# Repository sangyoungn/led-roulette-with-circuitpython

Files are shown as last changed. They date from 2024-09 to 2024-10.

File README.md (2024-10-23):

# LED Roulette with CircuitPython

This is a project to build an LED roulette with CircuitPython on EFR32xG24 Explorer Kit.

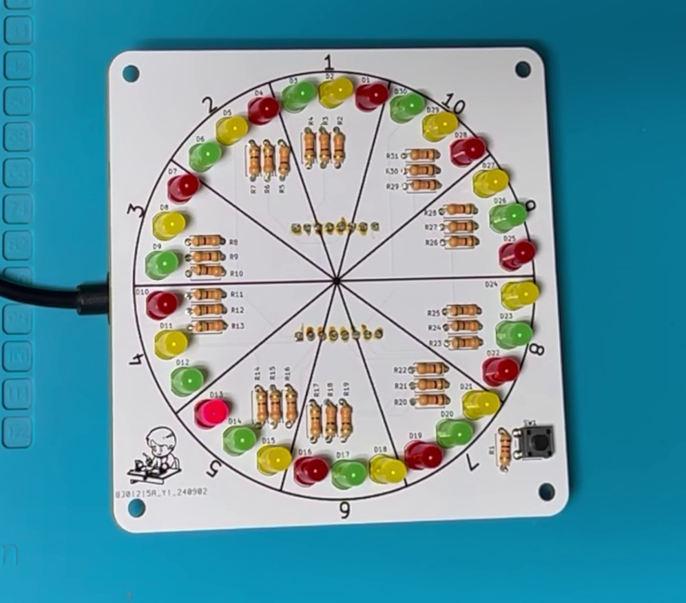
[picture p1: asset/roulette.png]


## Contents

"**hardware**" directory contains files for the hardware design including schematic and gerber output.
"**code**" directry contains scripts written in CircuitPython, which run on EFR32xG24 Explorer Kit.

## Directory Structure

.   
├── **hardware**   
|&nbsp;&nbsp;&nbsp;&nbsp;&nbsp;└── **roulette** (KiCad Design Directory)   
|&nbsp;&nbsp;&nbsp;&nbsp;&nbsp;&nbsp;&nbsp;&nbsp;&nbsp;&nbsp;├── **gerber** (PCB Gerber Plot Directory)   
|&nbsp;&nbsp;&nbsp;&nbsp;&nbsp;&nbsp;&nbsp;&nbsp;&nbsp;&nbsp;├── **pdf** (PCB PDF Polt Directory)   
|&nbsp;&nbsp;&nbsp;&nbsp;&nbsp;&nbsp;&nbsp;&nbsp;&nbsp;&nbsp;├── *roulette.dxf* (PCB Outline and Decoration Silk DXF)   
|&nbsp;&nbsp;&nbsp;&nbsp;&nbsp;&nbsp;&nbsp;&nbsp;&nbsp;&nbsp;├── *roulette.kicad_pcb* (PCB Design File)   
|&nbsp;&nbsp;&nbsp;&nbsp;&nbsp;&nbsp;&nbsp;&nbsp;&nbsp;&nbsp;├── *roulette.kicad_pro* (KiCad Project File)   
|&nbsp;&nbsp;&nbsp;&nbsp;&nbsp;&nbsp;&nbsp;&nbsp;&nbsp;&nbsp;├── *roulette.pdf* (PDF Plot File of Whole Schematic)   
|&nbsp;&nbsp;&nbsp;&nbsp;&nbsp;&nbsp;&nbsp;&nbsp;&nbsp;&nbsp;├── *roulette.kicad_sch* (Schematic File #1)   
|&nbsp;&nbsp;&nbsp;&nbsp;&nbsp;&nbsp;&nbsp;&nbsp;&nbsp;&nbsp;├── *LEDs.kicad_sch* (Schematic File #2)    
|&nbsp;&nbsp;&nbsp;&nbsp;&nbsp;&nbsp;&nbsp;&nbsp;&nbsp;&nbsp;└── *xg24_explorer_kit.kicad_sch* (Schematic File #3)   
└── **code**   
&nbsp;&nbsp;&nbsp;&nbsp;&nbsp;├── *code.py*   
&nbsp;&nbsp;&nbsp;&nbsp;&nbsp;└── *led_roulette.py*   

Refer to clips in the link for more information.

https://youtube.com/playlist?list=PLlT0qmKc0_5ddENmn3fNbMIVXvFqQTv2Z&si=PHfeczIfOtfNPaJ8

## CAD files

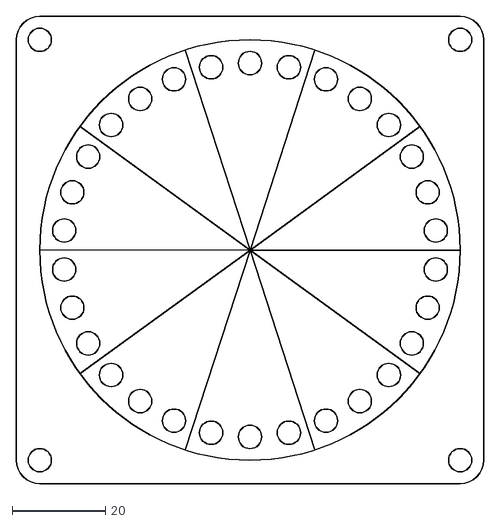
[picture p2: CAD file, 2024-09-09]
hardware/roulette/roulette.dxf
100.0 x 100.0

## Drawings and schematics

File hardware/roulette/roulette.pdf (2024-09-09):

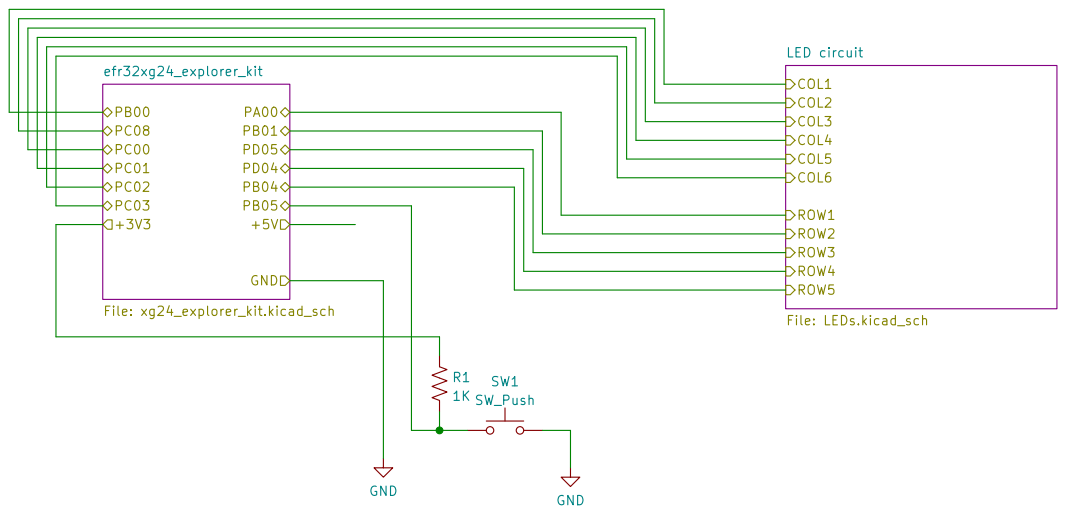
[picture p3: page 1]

File: roulette.kicad_sch Sheet: /
Id: 1/3 Title: LED Roulette

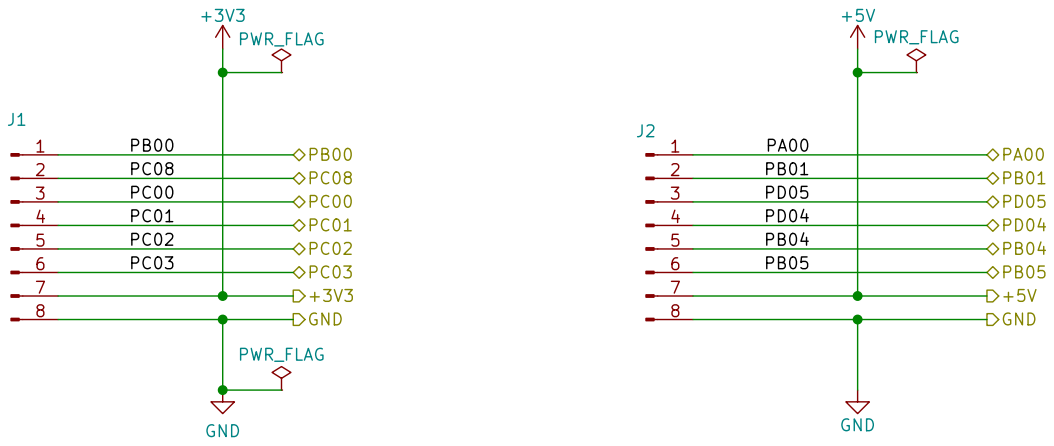
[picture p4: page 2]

Sheet: /efr32xg24_explorer_kit/
File: xg24_explorer_kit.kicad_sch
Id: 2/3 Title: EFR32xG24 Explorer Kit

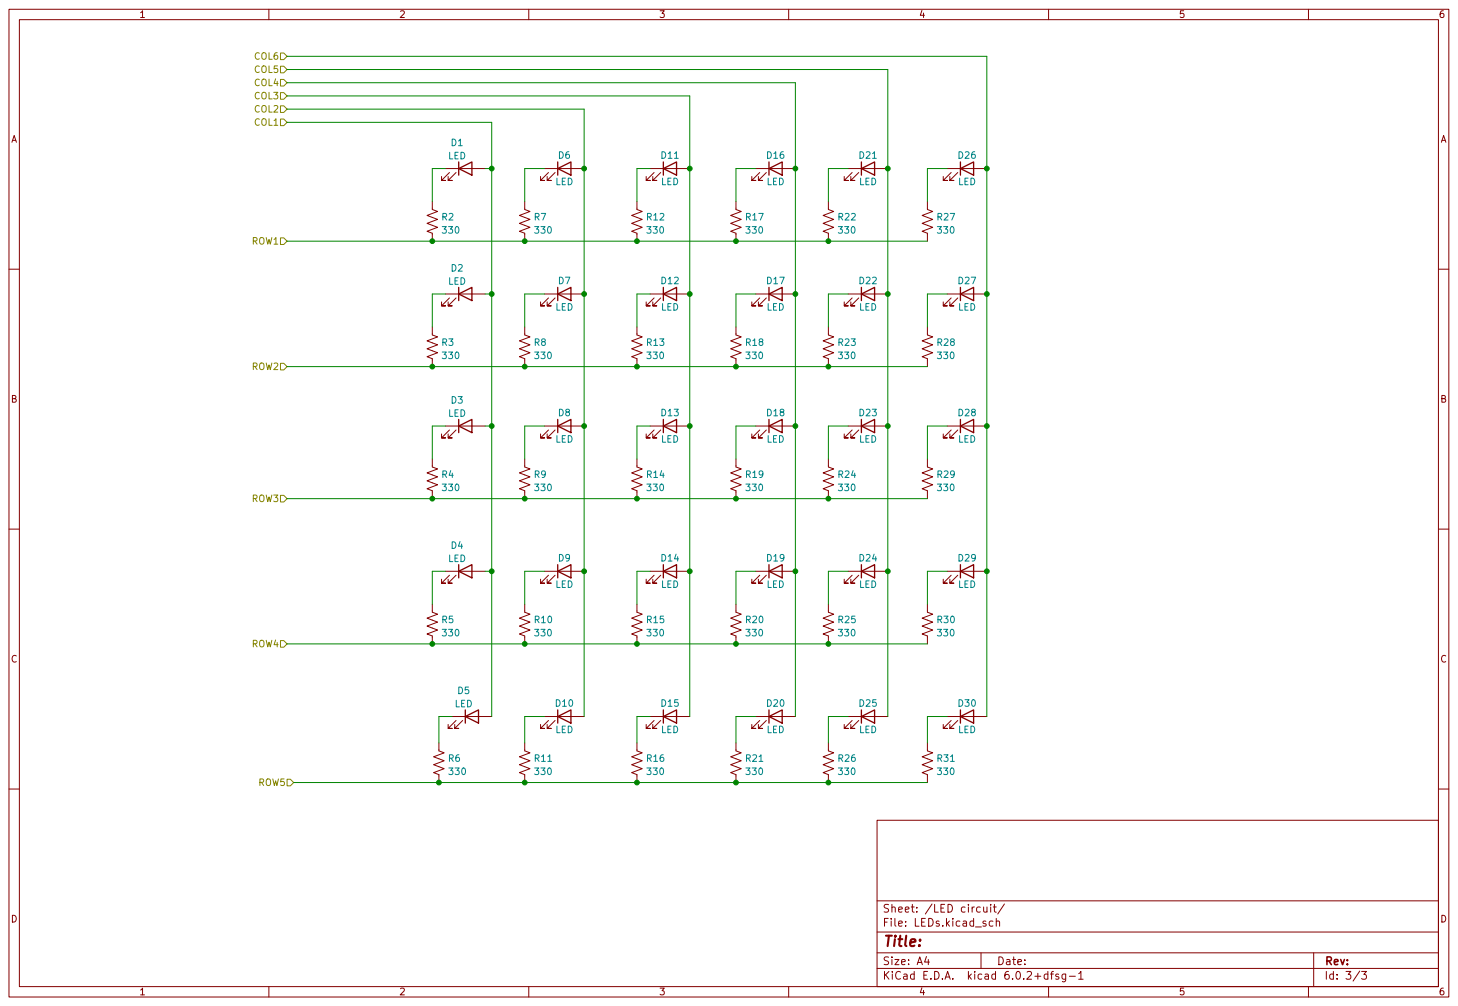
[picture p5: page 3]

File: LEDs.kicad_sch Sheet: /LED circuit/ R26

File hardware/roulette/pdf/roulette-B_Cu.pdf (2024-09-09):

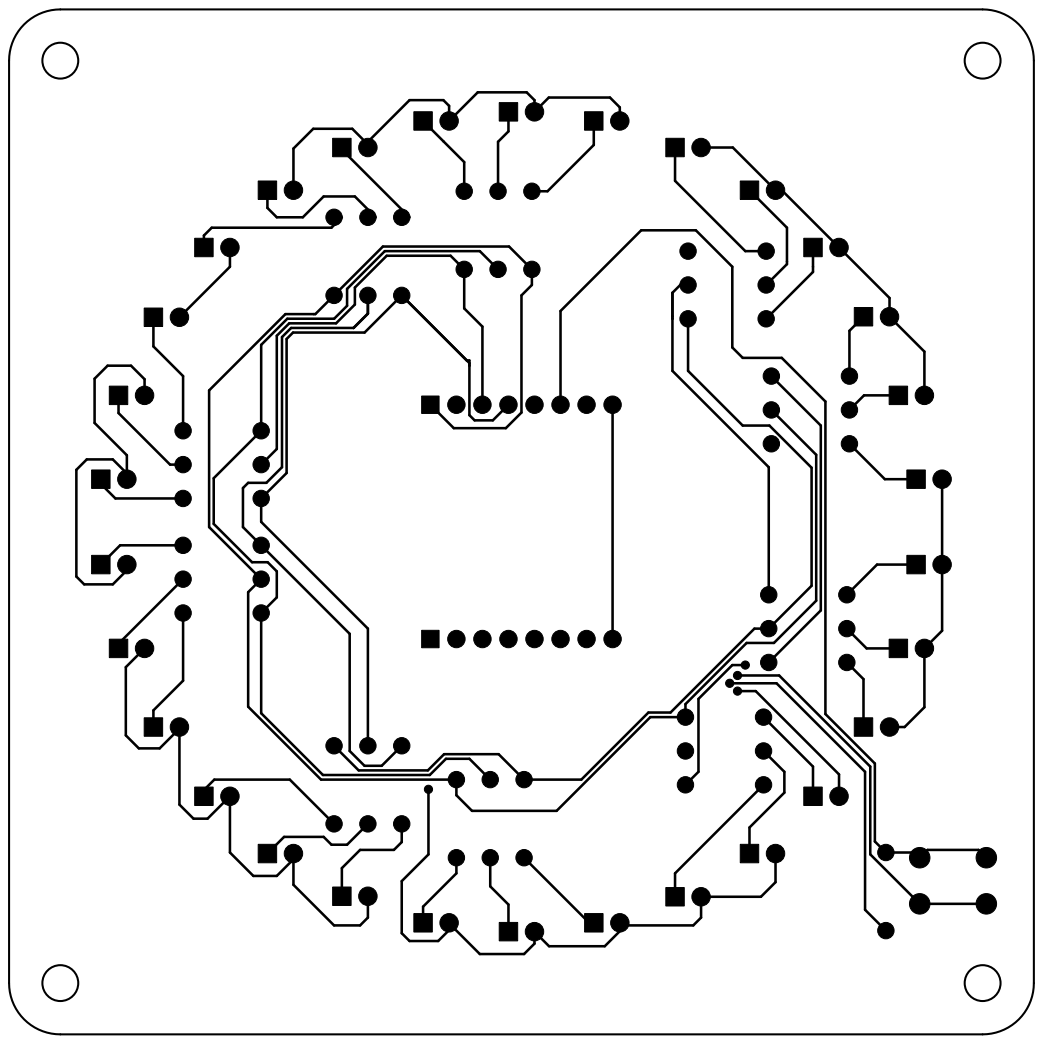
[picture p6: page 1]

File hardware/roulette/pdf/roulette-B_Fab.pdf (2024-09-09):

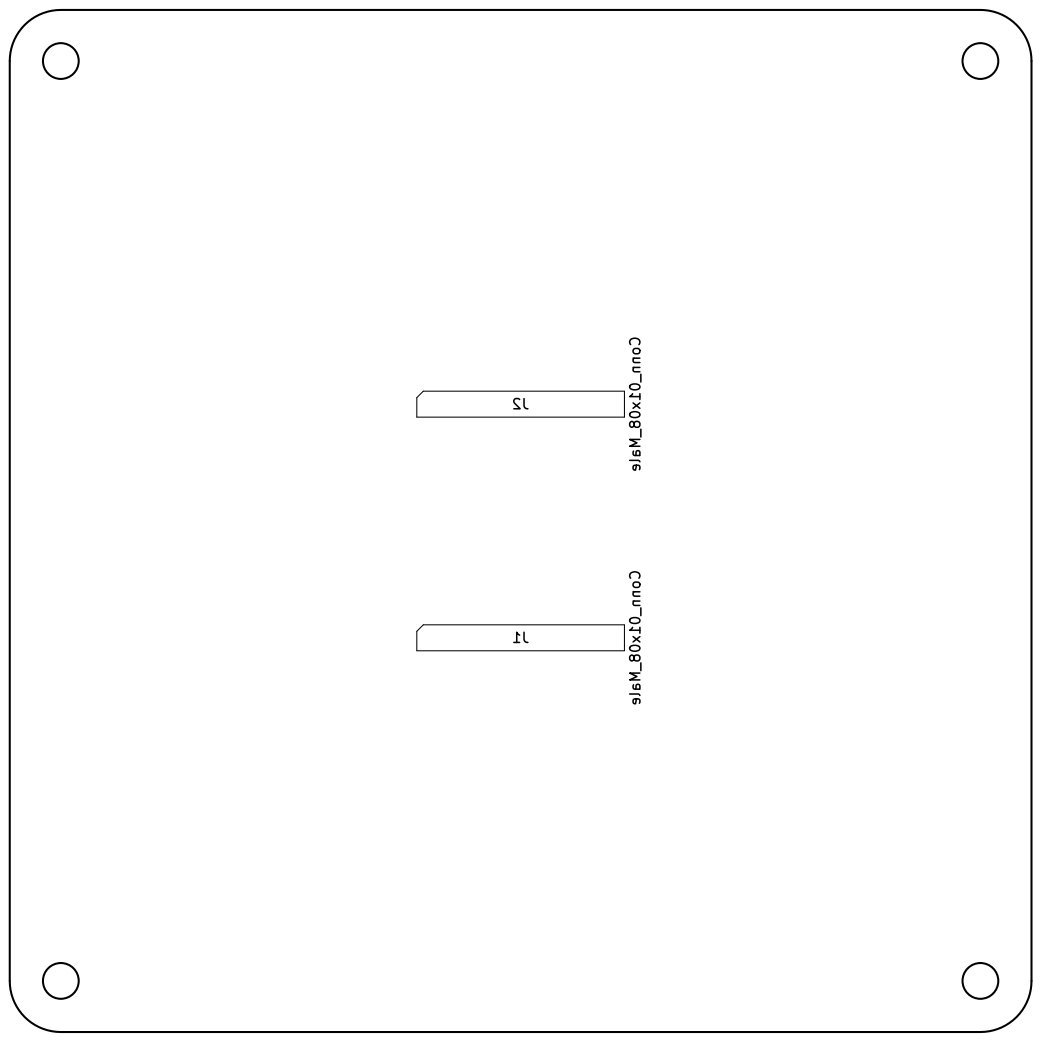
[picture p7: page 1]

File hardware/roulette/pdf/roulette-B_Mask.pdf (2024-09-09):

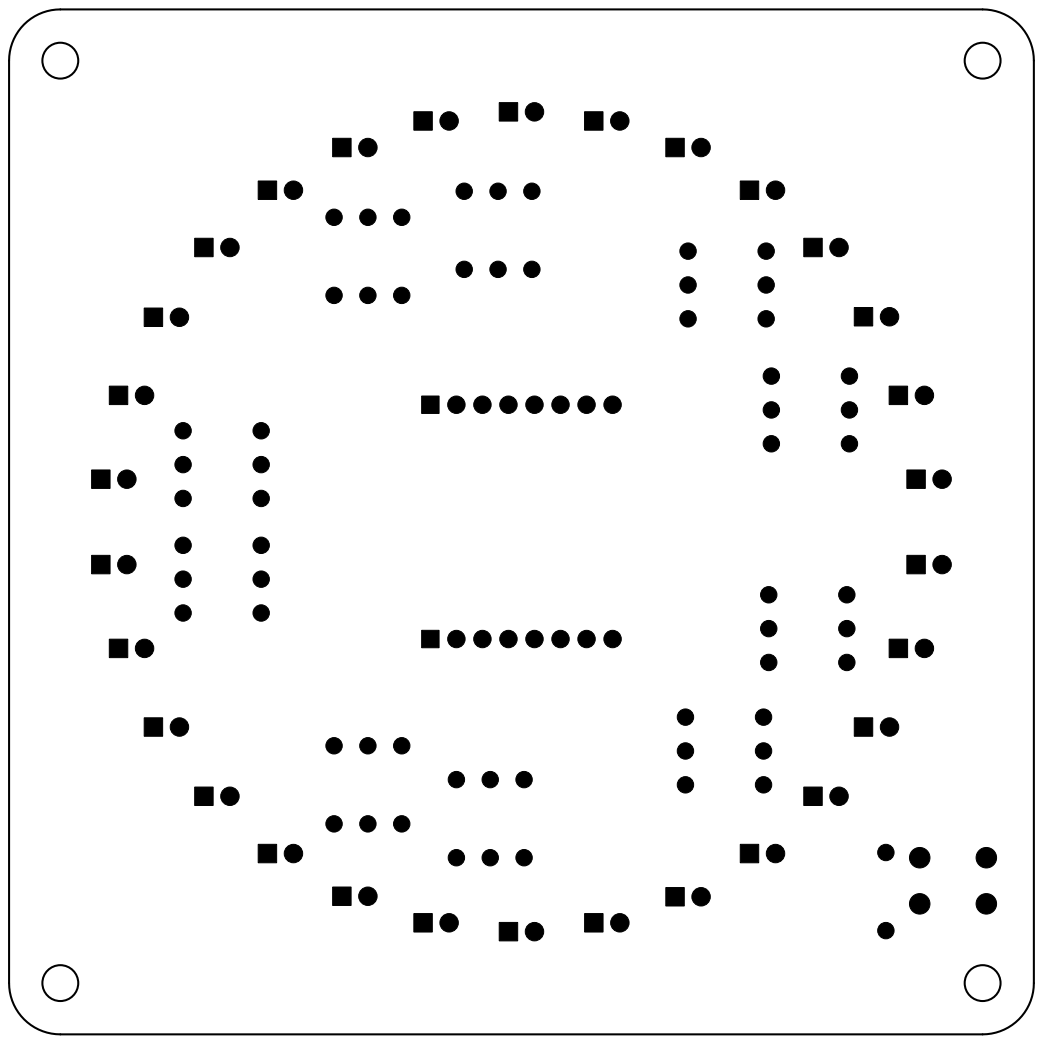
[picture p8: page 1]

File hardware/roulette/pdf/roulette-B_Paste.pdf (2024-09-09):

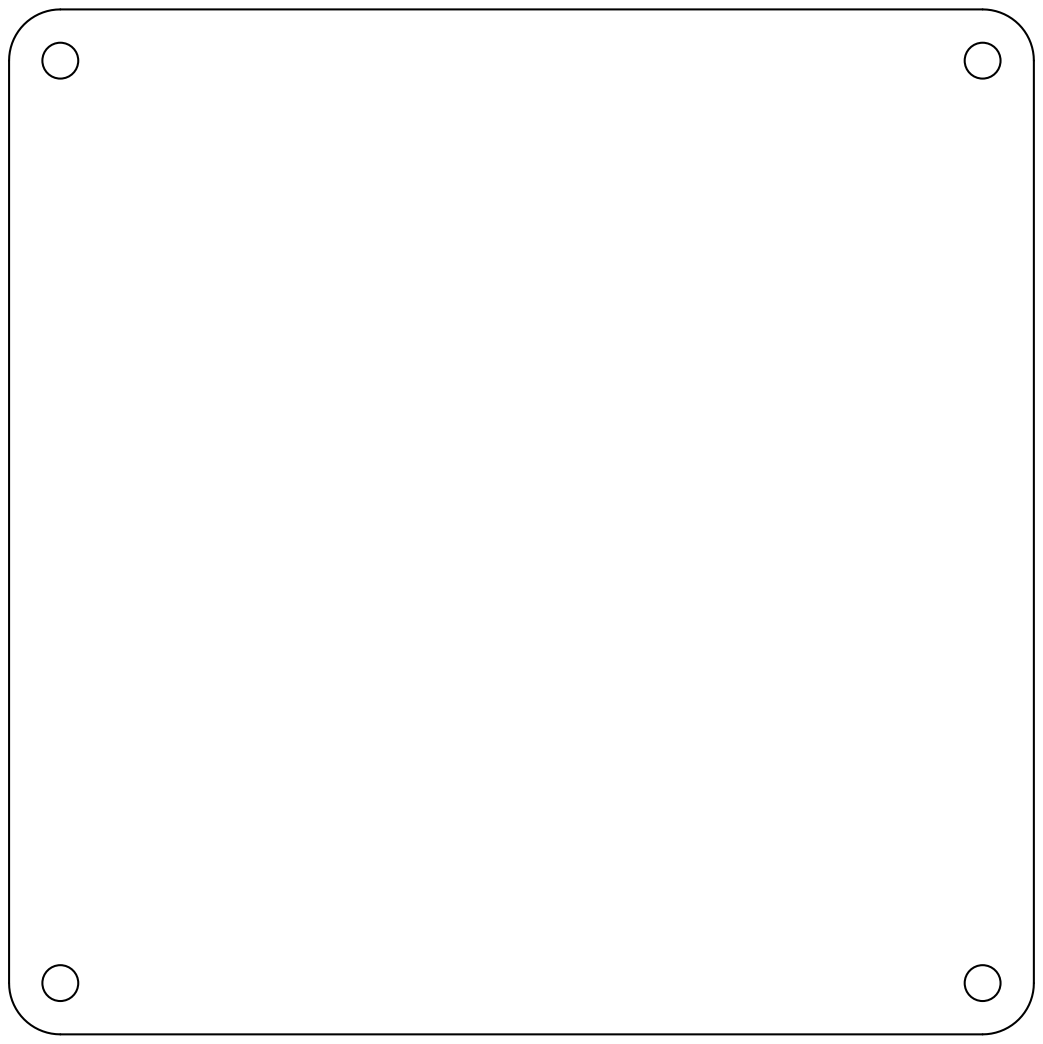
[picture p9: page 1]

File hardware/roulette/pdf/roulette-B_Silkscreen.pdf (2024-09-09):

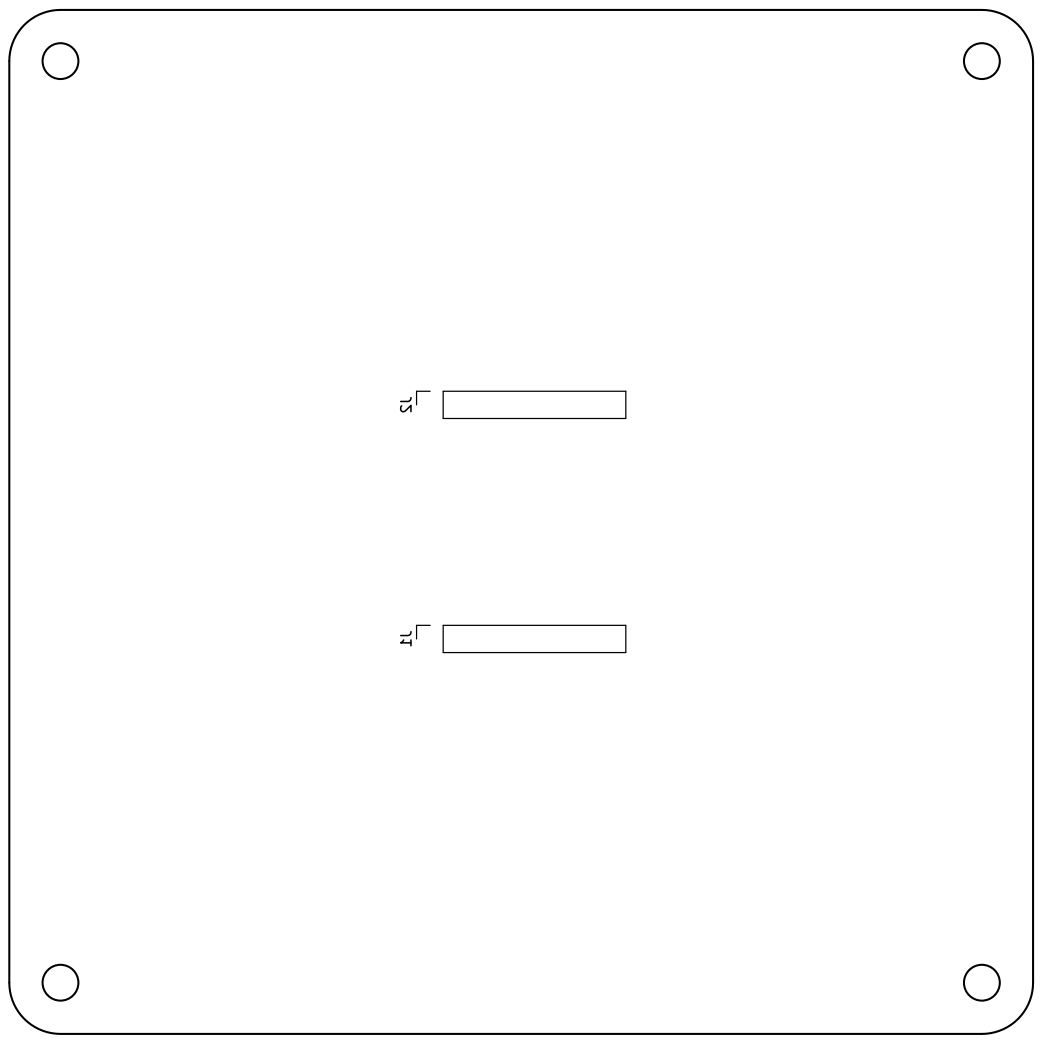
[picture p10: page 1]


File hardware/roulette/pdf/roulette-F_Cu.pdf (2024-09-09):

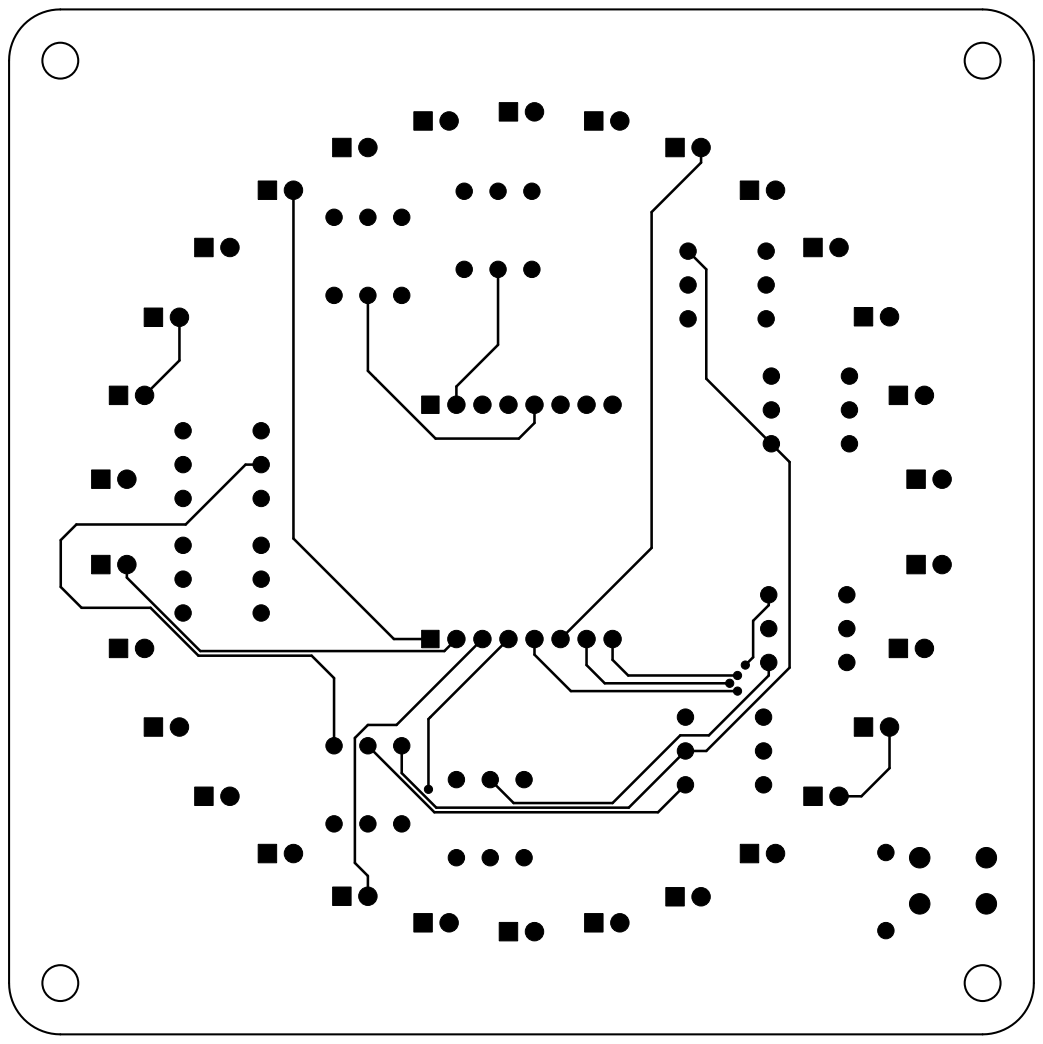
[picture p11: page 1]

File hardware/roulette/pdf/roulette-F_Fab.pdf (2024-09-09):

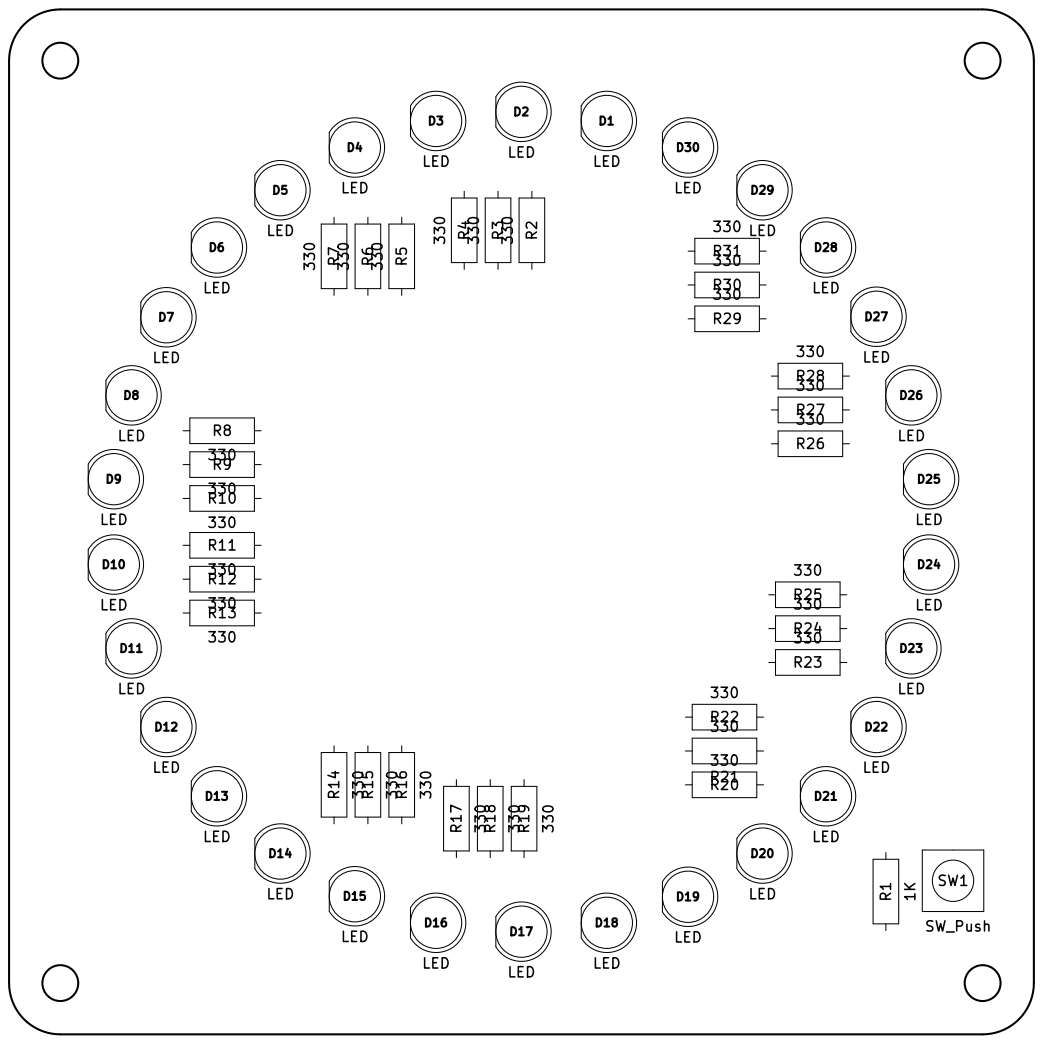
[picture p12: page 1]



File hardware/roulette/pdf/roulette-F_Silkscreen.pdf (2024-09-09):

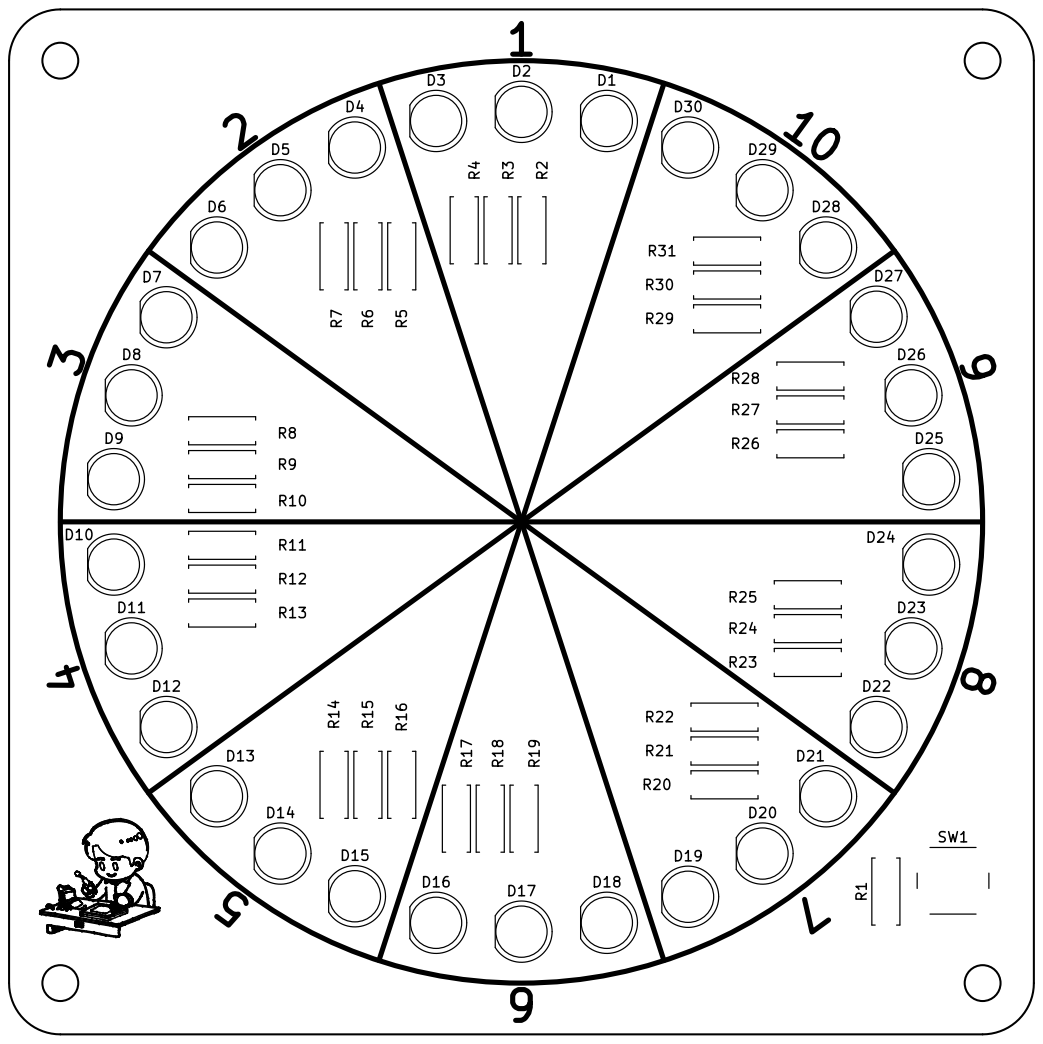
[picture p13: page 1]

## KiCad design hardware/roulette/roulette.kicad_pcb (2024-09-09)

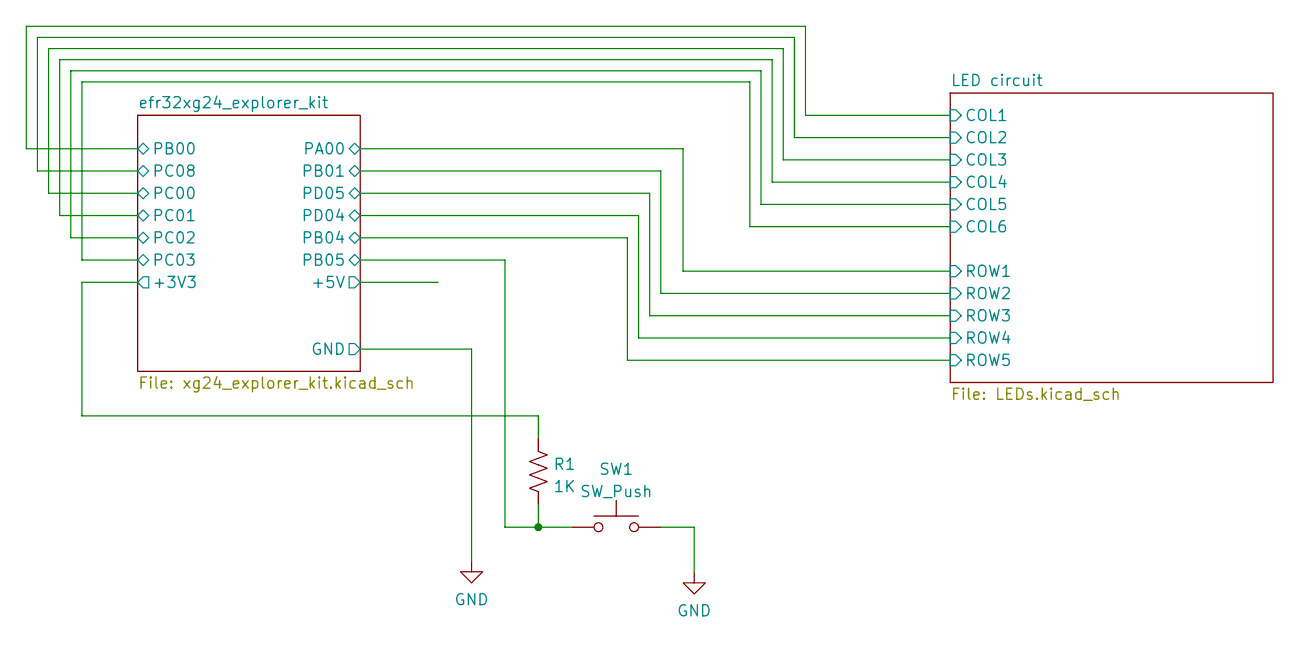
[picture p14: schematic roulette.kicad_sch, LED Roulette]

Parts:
R1: 1K; R_Axial_DIN0207_L6.3mm_D2.5mm_P7.62mm_Horizontal
SW1: SW_Push; SW_PUSH_6mm

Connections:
+3V3: R1.1; also elsewhere on the board
/efr32xg24_explorer_kit/PB05: R1.2, SW1.1; also elsewhere on the board
GND: SW1.2; also elsewhere on the board

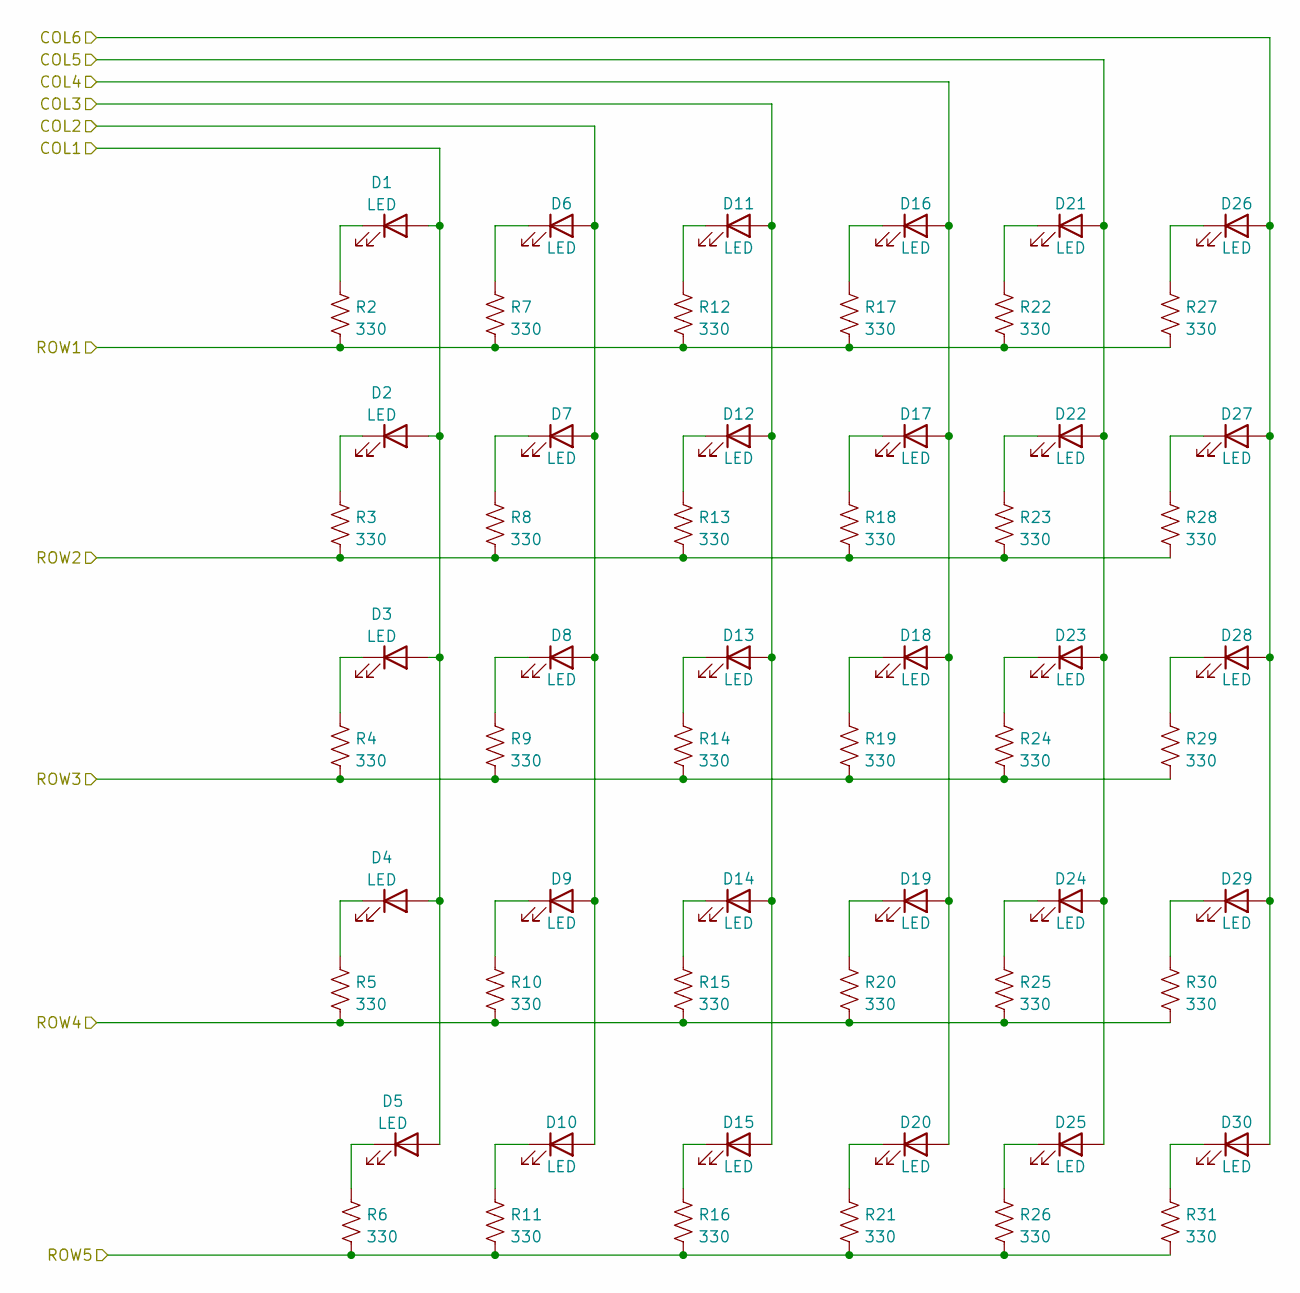
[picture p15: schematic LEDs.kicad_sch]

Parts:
D1, D2, D3, D4, D5, D6, D7, D8, D9, D10, D11, D12, D13, D14, D15, D16, D17, D18, D19, D20, D21, D22, D23, D24, D25, D26, D27, D28, D29, D30: LED; LED_D5.0mm
R2, R3, R4, R5, R6, R7, R8, R9, R10, R11, R12, R13, R14, R15, R16, R17, R18, R19, R20, R21, R22, R23, R24, R25, R26, R27, R28, R29, R30, R31: 330; R_Axial_DIN0207_L6.3mm_D2.5mm_P7.62mm_Horizontal

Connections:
/efr32xg24_explorer_kit/PA00: R2.2, R7.2, R12.2, R17.2, R22.2, R27.2; also elsewhere on the board
/efr32xg24_explorer_kit/PB00: D1.2 (A), D2.2 (A), D3.2 (A), D4.2 (A), D5.2 (A); also elsewhere on the board
/efr32xg24_explorer_kit/PB01: R3.2, R8.2, R13.2, R18.2, R23.2, R28.2; also elsewhere on the board
/efr32xg24_explorer_kit/PB04: R6.2, R11.2, R16.2, R21.2, R26.2, R31.2; also elsewhere on the board
/efr32xg24_explorer_kit/PC00: D11.2 (A), D12.2 (A), D13.2 (A), D14.2 (A), D15.2 (A); also elsewhere on the board
/efr32xg24_explorer_kit/PC01: D16.2 (A), D17.2 (A), D18.2 (A), D19.2 (A), D20.2 (A); also elsewhere on the board
/efr32xg24_explorer_kit/PC02: D21.2 (A), D22.2 (A), D23.2 (A), D24.2 (A), D25.2 (A); also elsewhere on the board
/efr32xg24_explorer_kit/PC03: D26.2 (A), D27.2 (A), D28.2 (A), D29.2 (A), D30.2 (A); also elsewhere on the board
/efr32xg24_explorer_kit/PC08: D6.2 (A), D7.2 (A), D8.2 (A), D9.2 (A), D10.2 (A); also elsewhere on the board
/efr32xg24_explorer_kit/PD04: R5.2, R10.2, R15.2, R20.2, R25.2, R30.2; also elsewhere on the board
/efr32xg24_explorer_kit/PD05: R4.2, R9.2, R14.2, R19.2, R24.2, R29.2; also elsewhere on the board
unnamed: D1.1 (K), R2.1
unnamed: D2.1 (K), R3.1
unnamed: D3.1 (K), R4.1
unnamed: D4.1 (K), R5.1
unnamed: D5.1 (K), R6.1
unnamed: D6.1 (K), R7.1
unnamed: D7.1 (K), R8.1
unnamed: D8.1 (K), R9.1
unnamed: D9.1 (K), R10.1
unnamed: D10.1 (K), R11.1
unnamed: D11.1 (K), R12.1
unnamed: D12.1 (K), R13.1
unnamed: D13.1 (K), R14.1
unnamed: D14.1 (K), R15.1
unnamed: D15.1 (K), R16.1
unnamed: D16.1 (K), R17.1
unnamed: D17.1 (K), R18.1
unnamed: D18.1 (K), R19.1
unnamed: D19.1 (K), R20.1
unnamed: D20.1 (K), R21.1
unnamed: D21.1 (K), R22.1
unnamed: D22.1 (K), R23.1
unnamed: D23.1 (K), R24.1
unnamed: D24.1 (K), R25.1
unnamed: D25.1 (K), R26.1
unnamed: D26.1 (K), R27.1
unnamed: D27.1 (K), R28.1
unnamed: D28.1 (K), R29.1
unnamed: D29.1 (K), R30.1
unnamed: D30.1 (K), R31.1

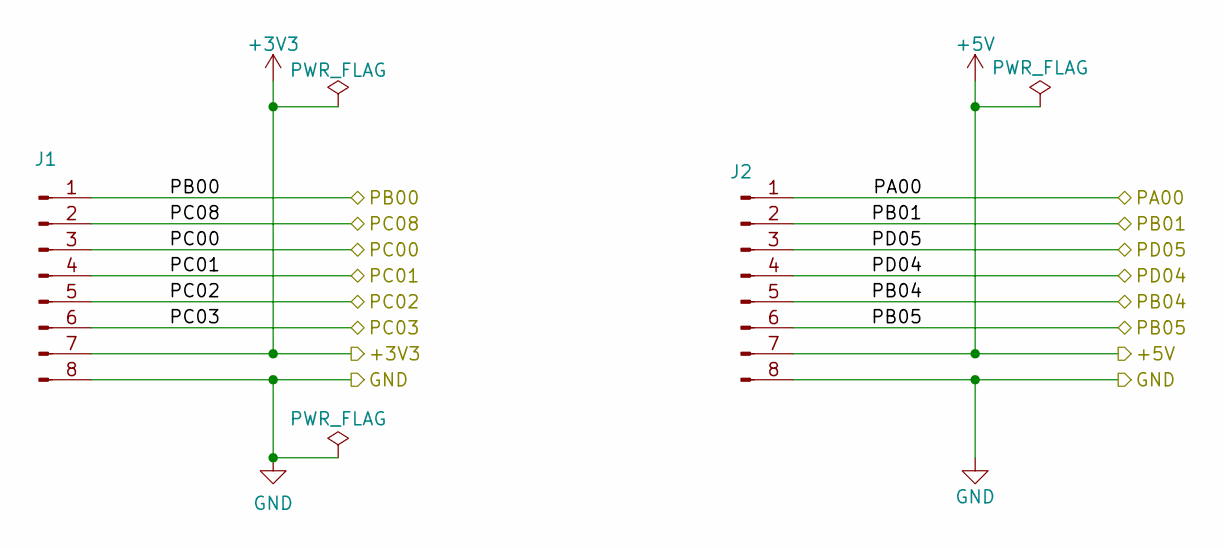
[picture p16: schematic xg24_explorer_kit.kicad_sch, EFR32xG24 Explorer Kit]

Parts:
J1, J2: Conn_01x08_Male; PinHeader_1x08_P2.54mm_Vertical

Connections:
+3V3: J1.7; also elsewhere on the board
+5V: J2.7
/efr32xg24_explorer_kit/PA00: J2.1; also elsewhere on the board
/efr32xg24_explorer_kit/PB00: J1.1; also elsewhere on the board
/efr32xg24_explorer_kit/PB01: J2.2; also elsewhere on the board
/efr32xg24_explorer_kit/PB04: J2.5; also elsewhere on the board
/efr32xg24_explorer_kit/PB05: J2.6; also elsewhere on the board
/efr32xg24_explorer_kit/PC00: J1.3; also elsewhere on the board
/efr32xg24_explorer_kit/PC01: J1.4; also elsewhere on the board
/efr32xg24_explorer_kit/PC02: J1.5; also elsewhere on the board
/efr32xg24_explorer_kit/PC03: J1.6; also elsewhere on the board
/efr32xg24_explorer_kit/PC08: J1.2; also elsewhere on the board
/efr32xg24_explorer_kit/PD04: J2.4; also elsewhere on the board
/efr32xg24_explorer_kit/PD05: J2.3; also elsewhere on the board
GND: J1.8, J2.8; also elsewhere on the board

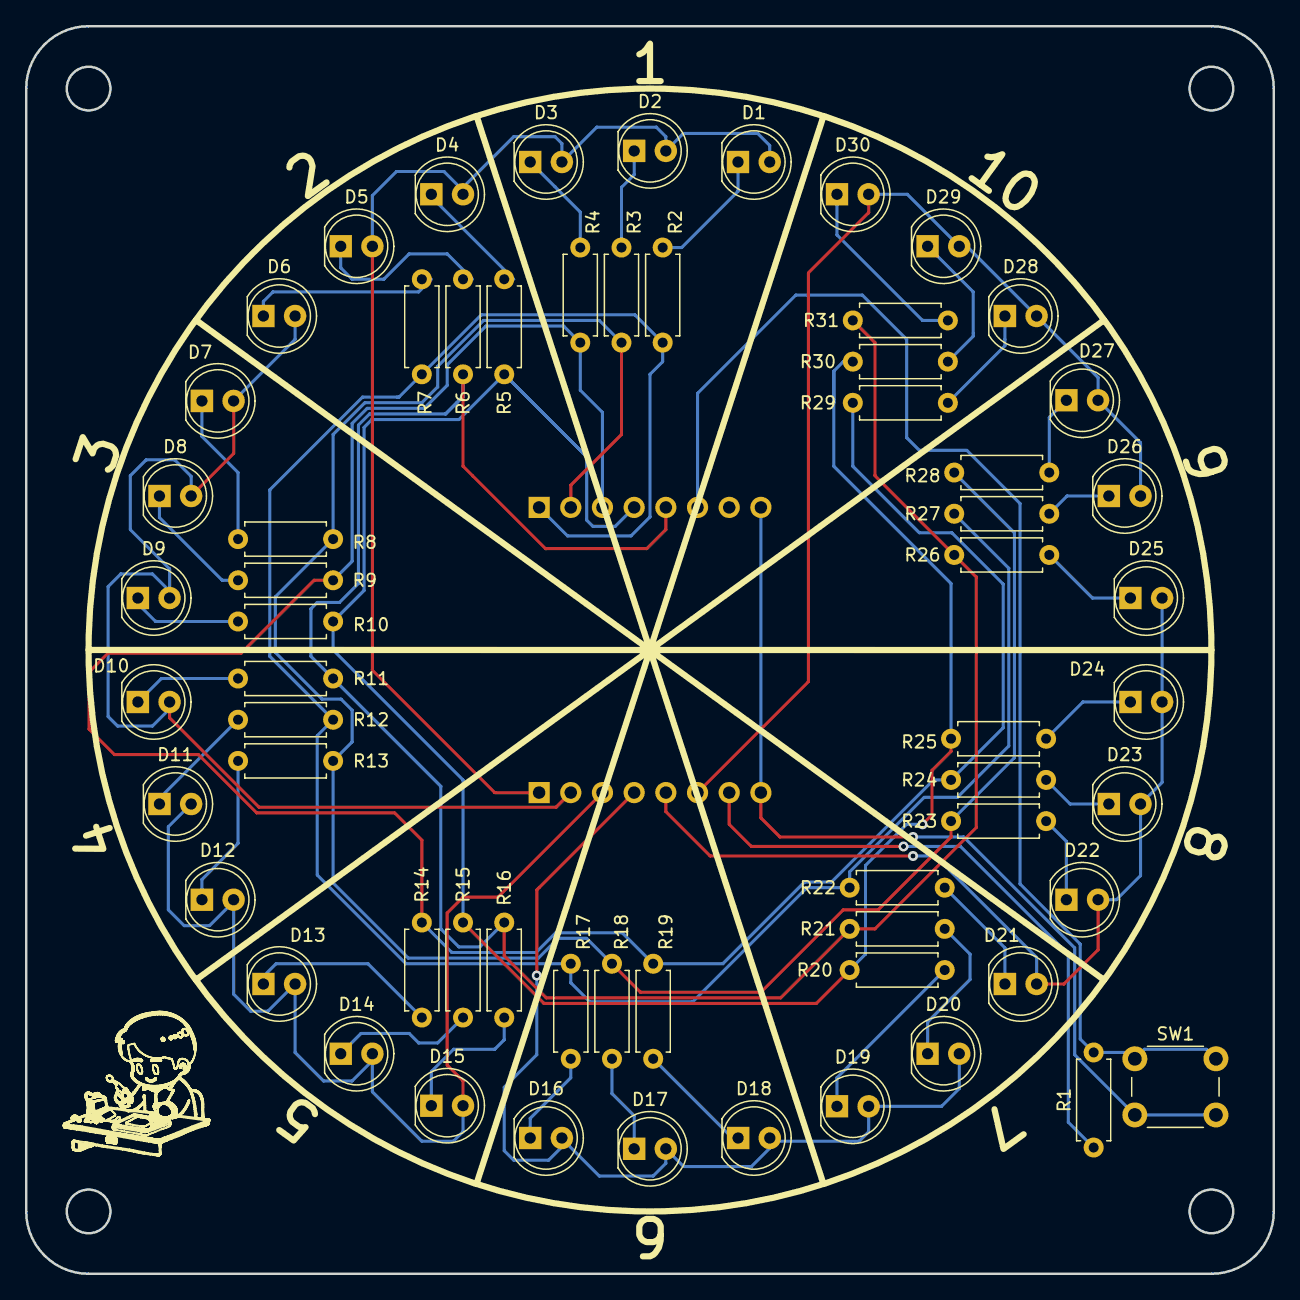
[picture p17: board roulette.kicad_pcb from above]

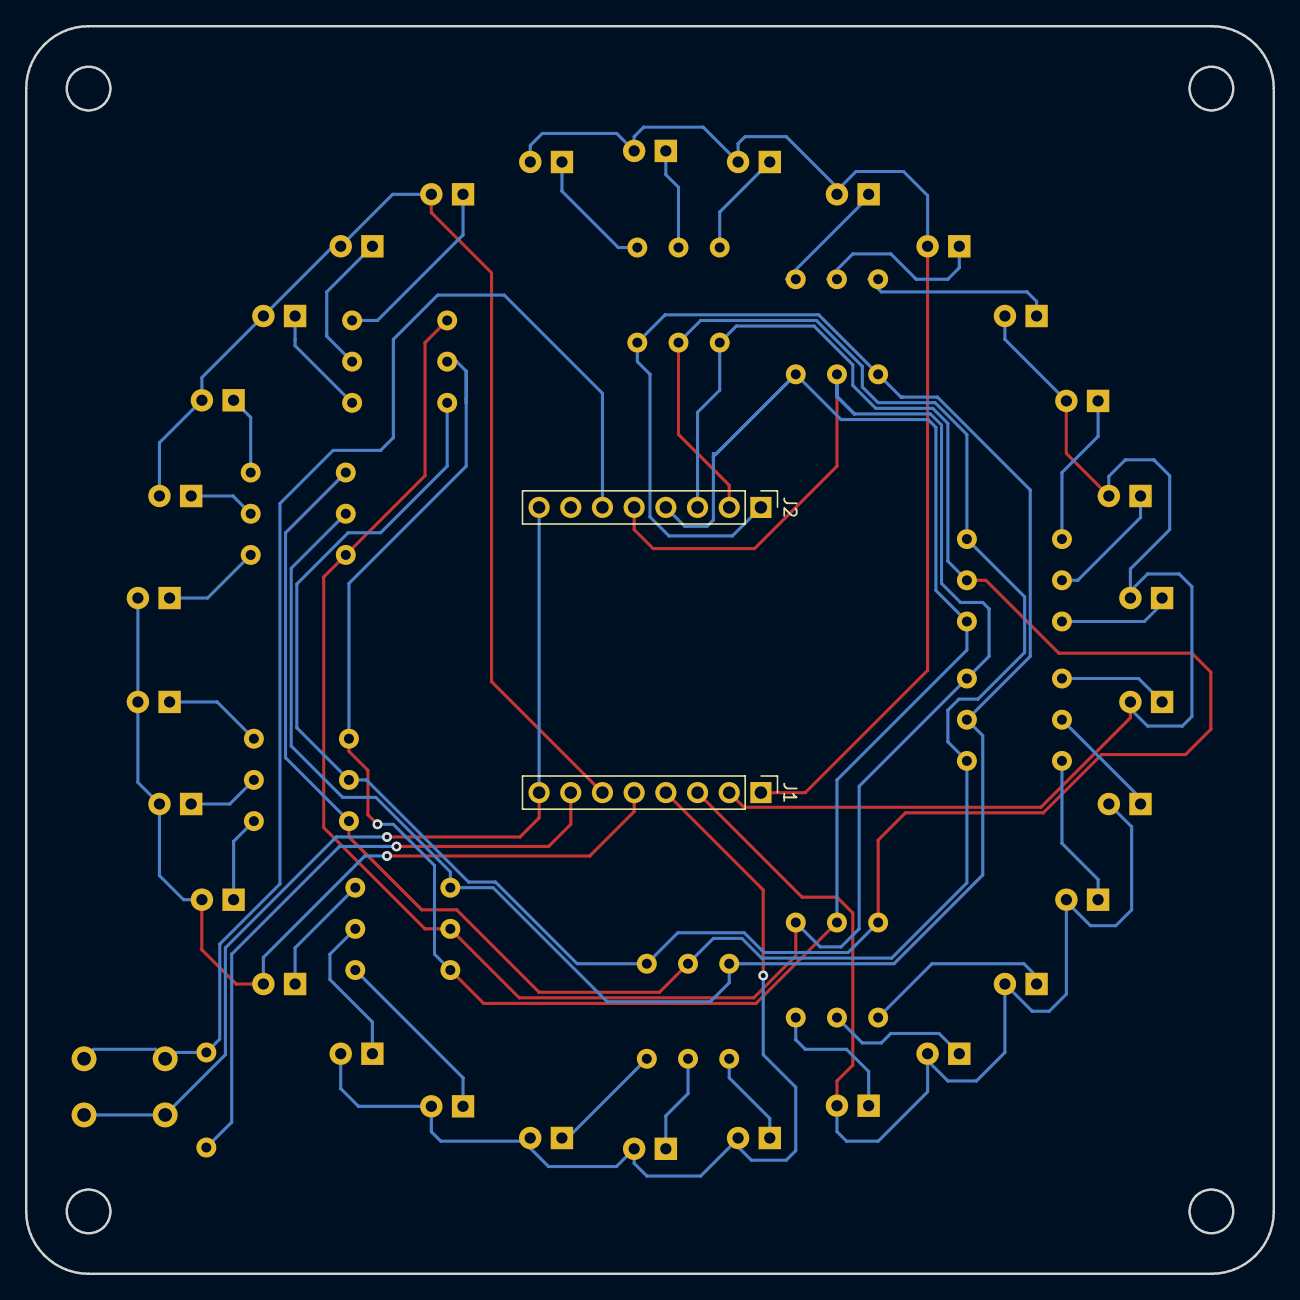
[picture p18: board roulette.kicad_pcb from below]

Board: 2 copper layers, 100.0 x 100.0 mm, 64 parts (2 on the bottom side), 44 nets.

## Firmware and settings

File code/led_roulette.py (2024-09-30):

import board
import digitalio
import random
import time

# debug = True
debug = False

def debug_print(str):
    if not debug:
        return
    print(str) # This will be executed only when debug == True.

class LED2:
    '''
    Class LED2 (version 2)
    Abstract LED with anode and cathode
    '''
    
    initialized_ports = {}
    
    def __init__(self, anode_port, cathode_port):
        if anode_port in LED2.initialized_ports: # Check if the anode_port already has been initialized.
            self.anode = LED2.initialized_ports[anode_port] # Use already initialized instance.
        else: # if not, newly initialize.
            self.anode = digitalio.DigitalInOut(anode_port)
            self.anode.direction = digitalio.Direction.OUTPUT
            LED2.initialized_ports[anode_port] = self.anode # Add to the dictionary.
        if cathode_port in LED2.initialized_ports: # Check if the cathode_port already has been initialized.
            self.cathode = LED2.initialized_ports[cathode_port] # Use already initialized instance.
        else: # if not, newly initialize.
            self.cathode = digitalio.DigitalInOut(cathode_port)
            self.cathode.direction = digitalio.Direction.OUTPUT
            LED2.initialized_ports[cathode_port] = self.cathode # Add to the dictionary.
            
        debug_print(LED2.initialized_ports)
        debug_print(self.anode)
        debug_print(self.cathode)
        
    def on(self):
        self.anode.value = True  # Anode --> High
        self.cathode.value = False # Cathode --> Low
        
    def off(self):
        self.anode.value = False # Anode --> Low
        self.cathode.value = True # Cathode --> High
        
class SWITCH:
    '''
    Class SWITCH
    Abstracts switch input over digital input port
    '''
    def __init__(self, port, polarity=False): # Polarity = True --> Active High
        self.port = digitalio.DigitalInOut(port)
        self.port.direction = digitalio.Direction.INPUT
        self.polarity = polarity
        
    def isPressed(self): # Returns True if SWITCH is pressed
        return not (self.polarity ^ self.port.value)

    def isReleased(self): # Returns True if SWITCH is released
        return not not (self.polarity ^ self.port.value)
    
class Roulette:
    '''
    Class Roulette
    '''
    def __init__(self, leds: list):
        '''
        [ D1, D2, D3, ......., D30 ]
        '''
        self.leds = leds
        self.off()
        
    def off(self, led=None):
        '''
        Turn off a specifed LED.
        If no LED is specified, turn off all LEDs.
        '''
        if led == None:
            for led in self.leds:
                led.off()
        else:
            self.leds[led].off()
            
    def on(self, led=None):
        '''
        Turn on a specifed LED.
        If no LED is specified, turn on all LEDs.
        '''
        if led == None:
            for led in self.leds:
                led.on()
        else:
            self.leds[led].on()
            
    def num_leds(self):
        '''
        Returns how many LEDs in this roulette
        '''
        num_leds = len(self.leds)
        debug_print(f"num_led = {num_leds}")
        return len(self.leds)
            
class Roulette_Game:
    '''
    Class Roulette_Game
    '''
    def __init__(self, roulette: Roulette):
        self.roulette = roulette
        
    def run(self):
        initial_run = random.randint(60,150)
        debug_print(f"Initial run = {initial_run}")
        index = random.randint(0, self.roulette.num_leds()-1)
        debug_print(f"Initial Index = {index}")
        interval = 0.05  # Initial interval = 50 msec
        
        debug_print("----- Initial Run -----")
        # Initial Run
        for run in range(initial_run):
            self.roulette.on(index)
            debug_print(f"Initial run index = {index}")
            time.sleep(interval)
            self.roulette.off(index)
            index += 1
            if index >= self.roulette.num_leds():
                index = 0
        
        debug_print("----- Roulette Run -----")
        # Roulette Run
        iter = random.randint(150, 300)
        debug_print(f"iter = {iter}")
        for run in range(iter):
            self.roulette.on(index)
            debug_print(f"Roulette run index = {index}")
            interval = 0.05 * (0.5/0.05) ** (run / iter) # Interval increases at each run
            time.sleep(interval)
            if run != iter-1:
                self.roulette.off(index)
            index += 1
            if index >= self.roulette.num_leds():
                index = 0
            
def roulette_main():
    switch = SWITCH(board.PB5)
    roulette = Roulette([\
        LED2(board.PB0, board.PA0), LED2(board.PB0, board.PB1), LED2(board.PB0, board.PD5), LED2(board.PB0, board.PD4), LED2(board.PB0, board.PB4),\
        LED2(board.PC8, board.PA0), LED2(board.PC8, board.PB1), LED2(board.PC8, board.PD5), LED2(board.PC8, board.PD4), LED2(board.PC8, board.PB4),\
        LED2(board.PC0, board.PA0), LED2(board.PC0, board.PB1), LED2(board.PC0, board.PD5), LED2(board.PC0, board.PD4), LED2(board.PC0, board.PB4),\
        LED2(board.PC1, board.PA0), LED2(board.PC1, board.PB1), LED2(board.PC1, board.PD5), LED2(board.PC1, board.PD4), LED2(board.PC1, board.PB4),\
        LED2(board.PC2, board.PA0), LED2(board.PC2, board.PB1), LED2(board.PC2, board.PD5), LED2(board.PC2, board.PD4), LED2(board.PC2, board.PB4),\
        LED2(board.PC3, board.PA0), LED2(board.PC3, board.PB1), LED2(board.PC3, board.PD5), LED2(board.PC3, board.PD4), LED2(board.PC3, board.PB4) \
        ])
    
    roulette.off()
    roulette_game = Roulette_Game(roulette)
    
    while True:
        while switch.isReleased():
            pass
        while switch.isPressed():
            roulette.on()
        roulette.off()
        roulette_game.run()
        
if __name__=="__main__":
    roulette_main()

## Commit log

2024-09-09 Hardware Design Work Included
    [LEDs.kicad_sch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]
2024-09-30 Added CircuitPython Code
